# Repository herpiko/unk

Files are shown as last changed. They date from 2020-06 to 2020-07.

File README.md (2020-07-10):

# UNK



UNK stands for Ultimate Ngoprek Keyboard, my own version of <a href="https://ultimatehackingkeyboard.com/">UHK</a>. Hope this will be my endgame (I know it's a lie) keyboard. ~~This is still a work-in-progress build logs.~~ <a href="https://github.com/herpiko/unk/blob/master/README.md#build-logs">The build logs is nearly complete</a>.

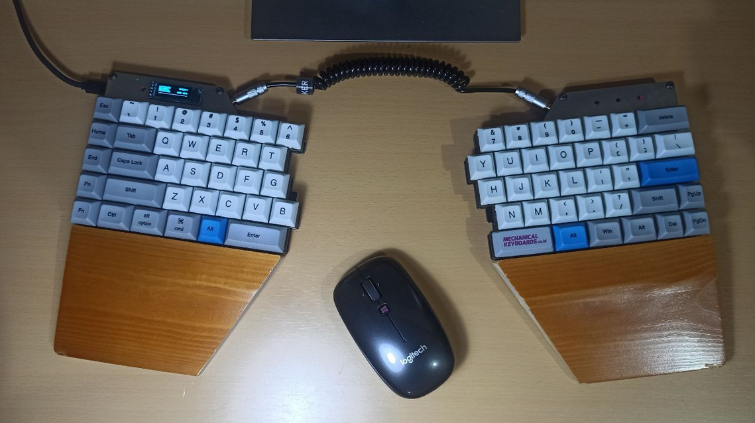
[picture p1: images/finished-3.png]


## Goals

- Cheap 👎
- As thin as possible (thinner than Vortex Core) 👎
- Fully programmable (QMK) ✅
- Almost zero learning curve (horizontally staggered, ~ortholinear~, ~symbols through modifier/layer~) ✅
- Ergonomic as UHK (splitted) ✅
- Generic size of keycaps (combinations from 104 keycaps set should be fitted) ✅
- Interchangeable middle modules (touchpad, trackball, smartphone dock) 👎

## Layout

- Combined : http://www.keyboard-layout-editor.com/#/gists/457787e3b1938c4cbe9d65c7b7bd31ef
- Left half: http://www.keyboard-layout-editor.com/#/gists/f117f3cbc2d0b1bf17206992068f9017
- Right half: http://www.keyboard-layout-editor.com/#/gists/e9e79566d1be71f77f1f2d33660011e5

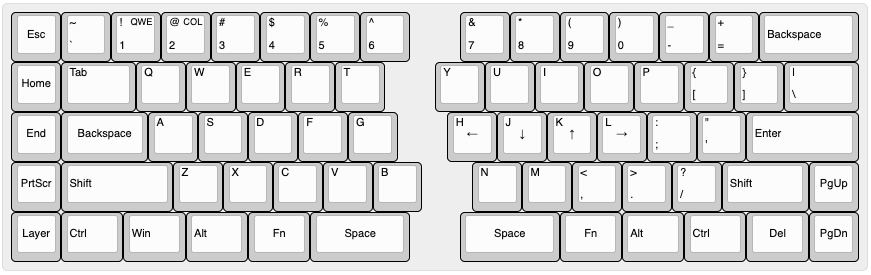
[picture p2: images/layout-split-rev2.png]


## Plate

Download:
- <a href="https://github.com/herpiko/unk/raw/master/unk-plate-layout.svg">SVG (Inkscape)</a>
- ~~<a href="https://github.com/herpiko/ultimate-ngoprek-keyboard/raw/master/split-full-final-cut.ai">Adobe Illustrator</a>~~

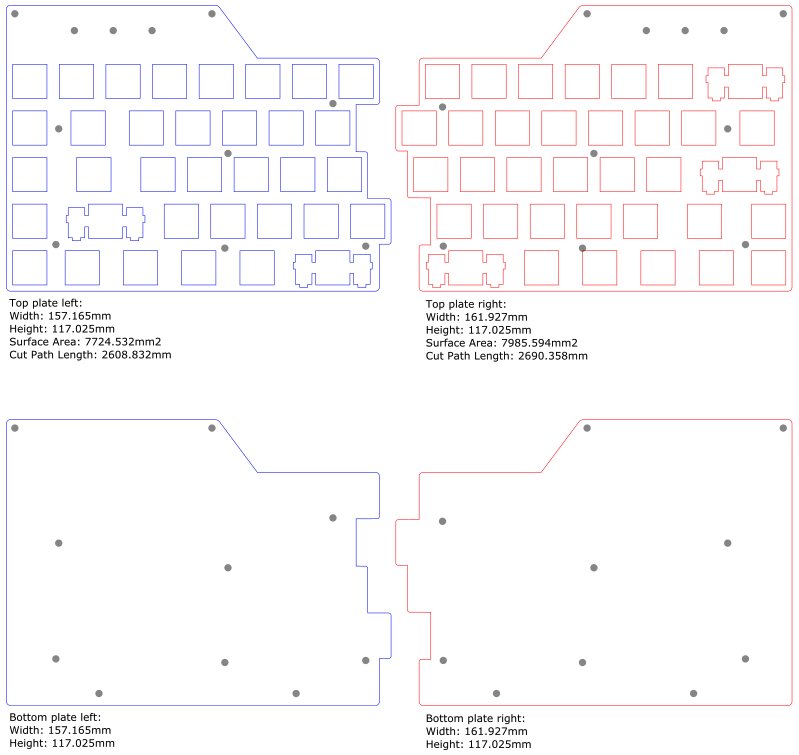
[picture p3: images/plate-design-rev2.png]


## Anatomy

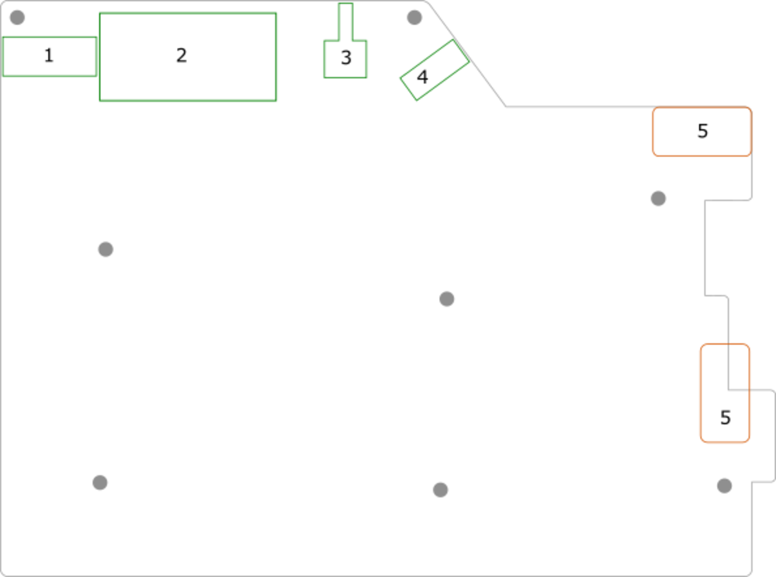
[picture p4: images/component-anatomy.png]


The greens are on the top plate. The oranges are on the bottom.

1. USB-C female to Micro USB male converter
2. Pro Micro clone
3. Tactile switch
4. TRRS jack
5. Neodymium magnets

## Parts

| Item  | Price (rupiah) |
| --- | ---: |
| I'm using existing DSA keycaps set from my <a href="https://www.google.com/search?q=vortex+tab+75&source=lnms&tbm=isch">Vortex Tab 75 keyboard</a>.<br/><br/>104 keycaps set is now supported. | 0 |
| <a href="https://www.tokopedia.com/vortexseries/ks-9-gateron-brown-switch-tactile-plate-mounted">Gateron Brown switches</a>, 80 @ Rp 2.400 | 192.000 |
| <a href="https://www.tokopedia.com/tokopuwei/dioda-in4148-1n-4148-in-4148-dip-diode-1n4148-do35-ac85-harga-1-pcs">IN4148 diodes</a>, 200 @ Rp 100 | 20.000 |
| <a href="https://www.tokopedia.com/solarperfect/pro-micro-promicro-atmega32u4-16mhz-5v-arduino-module">Pro micro ATMEGA32U4 16Mhz 5V</a>, 2 @ Rp 52.800 | 105.600 |
| Stainless steel plates + laser cutting service at <a href="https://www.instagram.com/laserindonesia/">Laser Indonesia</a>, 1.5mm top plate + 2.0mm bottom plate | 463.000 |
| ~~<a href="https://www.tokopedia.com/pixlup/genuine-cherry-pcb-mount-stabilizer-stabilizers-fullsize">Cherry switch stabilizers (1x6u, 6x2u)</a>~~  *<-- WRONG PART.* <a href="https://www.tokopedia.com/pixlup/genuine-cherry-plate-mount-stabilizers-stabilizer">The right one is the plate mount version.</a> | 210.000 |
| <a href="https://www.tokopedia.com/hpasesoris/m3x6mm-m3-6-black-nylon-hex-nut-m3-thread-female-standoff-spacer-aq21">M3 x 6mm female to female spacer</a>, 30 @ Rp 1.200 | 36.000 |
| <a href="https://www.tokopedia.com/pcmjakarta/kabel-tunggal-mini-tembaga-0-5mm-40meter">Single copper wire 0.5mm</a>, 40 meter | 30.000 |
| <a href="https://www.tokopedia.com/stickerkacafilm/stikerstickermotormobilstiker-karboncarbon3d-hitam-dof">Carbon vinyl sticker 30 meter</a> | 45.000 |
| <a href="https://www.tokopedia.com/kiddiesworld123/magnet-super-neodymium-kepingan-persegi-kotak-ndfeb-20-x-10-x-2-mm">Neodymium super magnet 20 x 10 x 2mm</a>, 16 @ Rp 3.700 | 59.200 |
| <a href="https://www.tokopedia.com/adelioberkah/baut-screw-kecil-m3x3-laptop-hp-toshiba-dell-samsung-asus-acer-lenovo">M3x3mm screw for top plate</a>, 20 @ Rp 3.000 | 60.000 |
| <a href="https://www.tokopedia.com/crd/m3-x-5mm-button-head-hex-screw-1pcs-baut-hex-m3x5mm-1pcs">M3x5mm hex screw for bottom plate</a>, 30 @ Rp 1.500 | 45.000 |
| <a href="https://www.bukalapak.com/p/komputer/aksesoris-226/keyboard/6ere8e-jual-wood-wrist-rest-for-tenkeyless-size-mechanical-keyboard-brown">Wood wrist rest for TKL size mechanical keyboard (36cm)</a> | 100.000 |
| <a href="https://www.tokopedia.com/qacc/type-c-to-microusb-adapter-converter-otg-adaptor-type-c-to-micro-usb">Type C USB to micro USB adapter</a>, 2 @ Rp 15.000 | 30.000 |
| <a href="https://www.bukalapak.com/p/elektronik/komponen-elektronik/zzdmgd-jual-tactile-switch-push-button-saklar-tekan-6x6x10-mm-arduino-elektronika-bread-board-pcb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">Tactile switch push button 6 x 6 x 10mm</a>, 2 @ Rp 2.800 | 5.600 |
| <a href="https://www.tokopedia.com/myofficialstore0/trrs-pcb-3-5mm-breakout-jack-headset-headphone-earphone-socket-diy-merah">TRRS PCB 3.5mm jack socket</a>, 2 @ Rp 12.000 | 24.000 |
| <a href="https://www.tokopedia.com/herzhz/35mm-trrs-4-pole-for-hifiman-balanced-male-plug-jack-35">3.5mm TRRS 4 pins male plug</a>, 2 @ Rp 12.500 | 25.000 |
| <a href="https://www.tokopedia.com/optimuspri/joyseus-2-in-1-coiled-data-cable-1-m-micro-usb-type-c">Joyseus 2 in 1 coiled data cable 1M (micro USB & type C)</a> | 45.000 |
| <a href="https://www.tokopedia.com/3mtapes/3m-sj-5306-bumpon-clear">3M SJ-5306 Bumpon Clear</a> | 18.000 |
| <a href="https://www.tokopedia.com/isee/new-091-091-inch-inchi-128x32-oled-white-display-lcd-module-slim">128x32 pixel OLED white display</a> | 35.000 |

*The list is excluding shipping cost and wrong parts those I purchased. Some items were purchased more than the need for spare/stockpile. If the whole things counted, it reached almost 2 million rupiahs.*

## Firmware

UNK firmware code is now registered under QMK's handwired section.

### Preparation
```
$ git clone https://github.com/qmk/qmk_firmware.git
$ ./util/qmk_install.sh
```

### Compile
```
$ make handwired/unk/rev1:default
```

### Flashing the left half

Press the reset button twice and fast, then:
```
$ sudo avrdude -p atmega32u4 -c avr109 -U ./.build/handwired_unk_rev1_default.hex -P /dev/ttyACM0

```

### Flashing the right half

Uncomment the line that state `#define MASTER_LEFT` in `keyboards/handwired/unk/rev1/config.h`, then:

```
$ make handwired/unk/rev1:default
```

Press the reset button twice and fast, then:

```
$ sudo avrdude -p atmega32u4 -c avr109 -U ./.build/handwired_unk_rev1_default.hex -P /dev/ttyACM0
```
## Usage

- `Layer` + `Home` to switch to Qwerty layout
- `Layer` + `End` to switch to Colemak layout

## Useful links

The sources I read and inspired me for building this keyboard:

- Keyboard layout editor, http://www.keyboard-layout-editor.com/
- Plate builder, http://builder.swillkb.com/
- Laser cutting service, https://lasergist.com/shop/lasergist/
- Acrylic laser cutting service, https://www.tokopedia.com/kencanagrafikama/akrilik-acrylic-3mm-potongan-custom-putih-susu
- Pro micro official guides/FAQ, https://learn.sparkfun.com/tutorials/pro-micro--fio-v3-hookup-guide/troubleshooting-and-faq
- Promethium51, https://priyadi.smugmug.com/Mechanical-Keyboard/Promethium-Keyboard/Build-Log/n-4fFNQC
- Handwiring split guide based on lets_split, https://johannes-jansson.github.io/projects/2018/07/23/hand-wiring-lets-split.html
- Handwiring guide, https://geekhack.org/index.php?topic=87689.0
- https://www.reddit.com/r/olkb/comments/5s8q76/help_pro_micro_pinout_for_qmk/
- Thinkpad trackpoint,
  - https://electronics.stackexchange.com/questions/189790/determining-trackpoint-pinout
  - https://github.com/qmk/qmk_firmware/tree/master/keyboards/handwired/trackpoint
  - https://github.com/alonswartz/trackpoint
  - https://github.com/alonswartz/trackpoint#tmk-firmware-changes-and-tweaks
  - https://docs.qmk.fm/#/feature_ps2_mouse
  - https://deskthority.net/wiki/TrackPoint_Hardware#ThinkPad_R61_TrackPoint
- Pro micro built-in LEDs, https://www.electronicsweekly.com/blogs/engineer-in-wonderland/arduino-micro-direct-access-board-leds-2017-08/
- TRRS in  Pro Micro + QMK, https://beta.docs.qmk.fm/using-qmk/hardware-features/feature_split_keyboard
- Blackberry trackpad, https://vlukash.com/2019/01/15/trackpad-in-keycap-corne-crkbd-keyboard/
- Adding layers, https://thomasbaart.nl/2018/12/06/qmk-basics-how-to-add-a-layer-to-your-keymap/
- Layers, https://jayliu50.github.io/qmk-cheatsheet/
- VIA configurator, https://gist.github.com/nooges/5878b2648b6daeefb5c44d4ec16bf912

## Build Logs

### 20200612

The wish was occured a loooooong time ago but I began to (seriously) design the keyboard from this date. I also started to purchase the parts that I need to build the keyboard.

### 20200615

Pro micro clones arrived. Small important things.

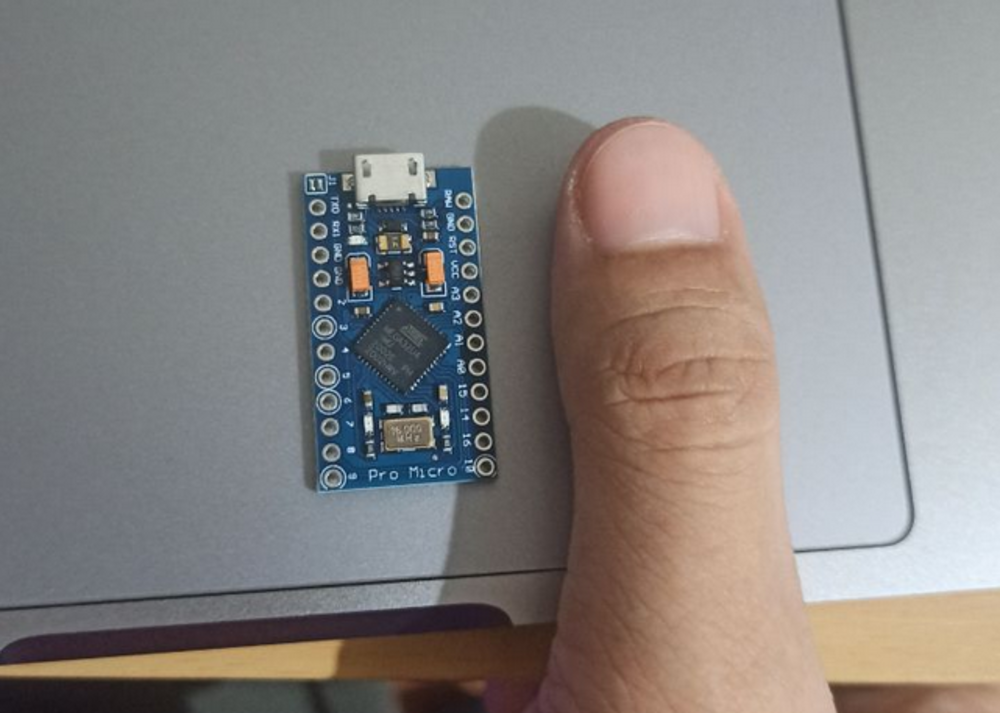
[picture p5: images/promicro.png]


### 20200617

The plates arrived. The top plate's thickness is 1.5mm and the bottom plate is 2mm. I'm a bit surprissed that these plates were quite heavy. Heavy (p)unk keyboard!

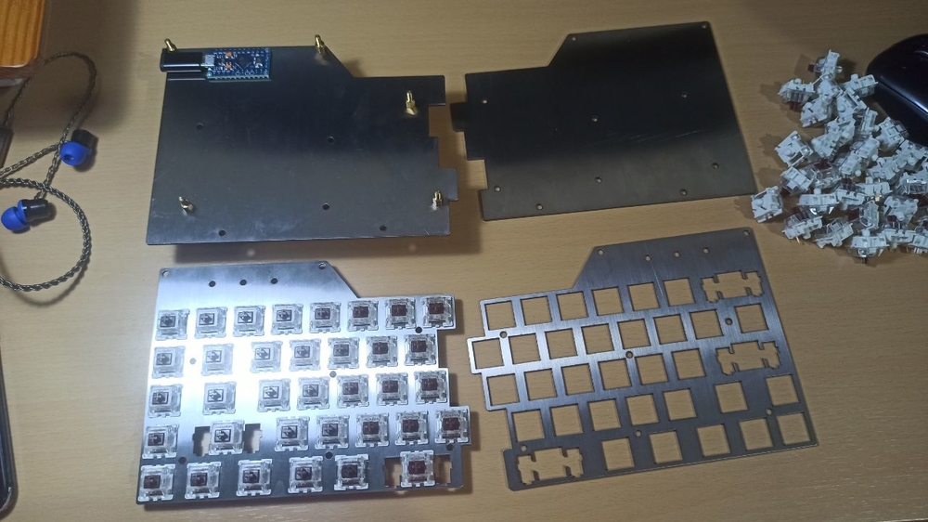
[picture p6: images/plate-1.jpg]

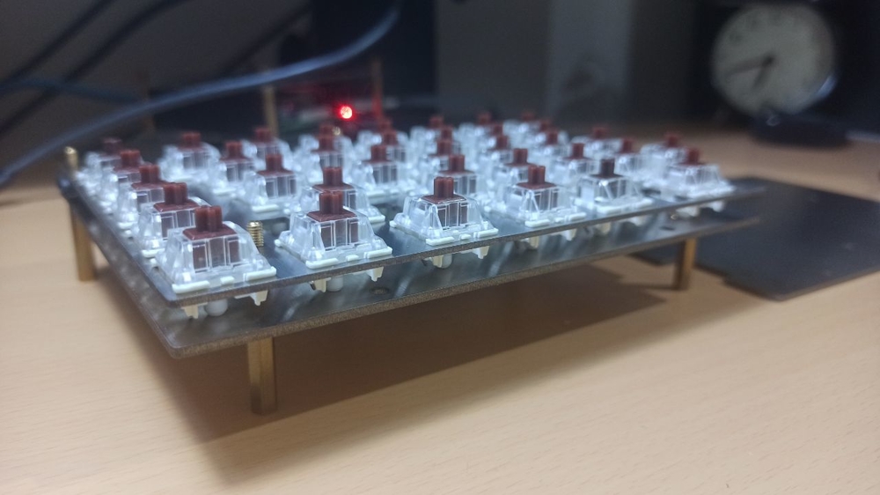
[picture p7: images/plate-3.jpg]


### 20200619

I put carbon-like sticker on the inner side of bottom plate to avoid shorting from the wiring.

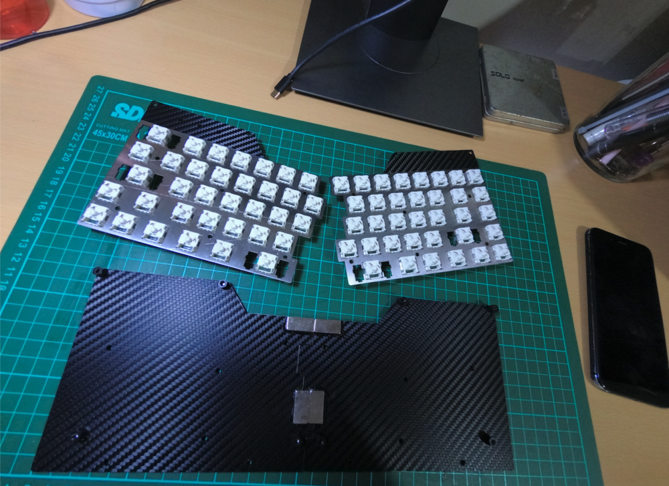
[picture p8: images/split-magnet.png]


Also there were four strong neodymium magnets to help the two parts stick together.



### 20200620

Handwired. Pardon my mediocre soldering skill.

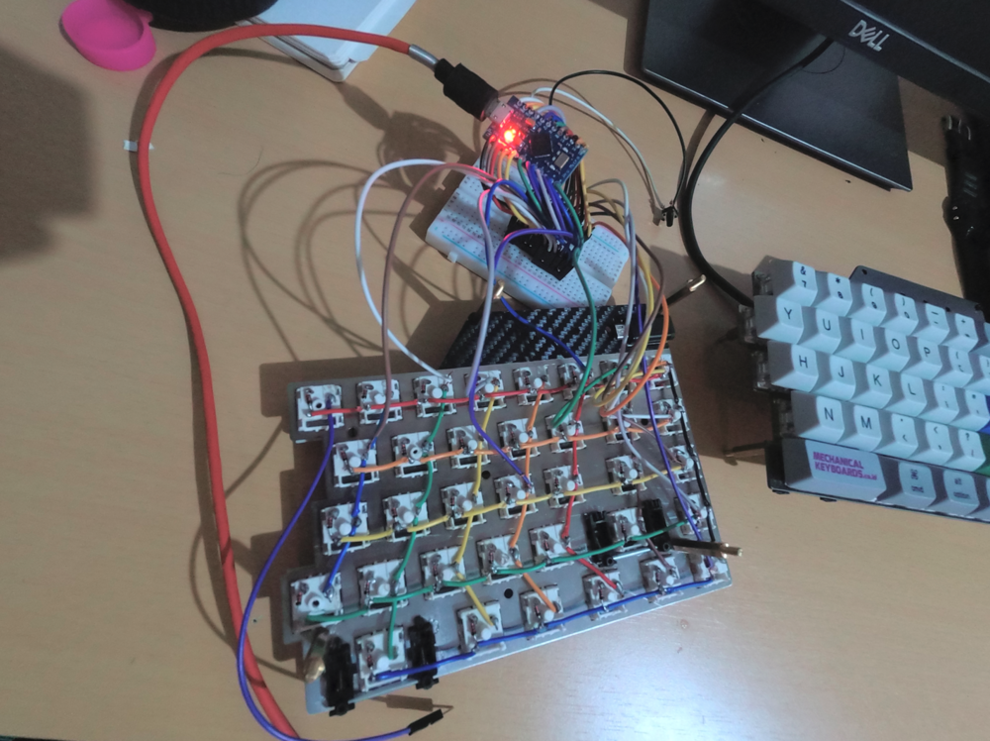
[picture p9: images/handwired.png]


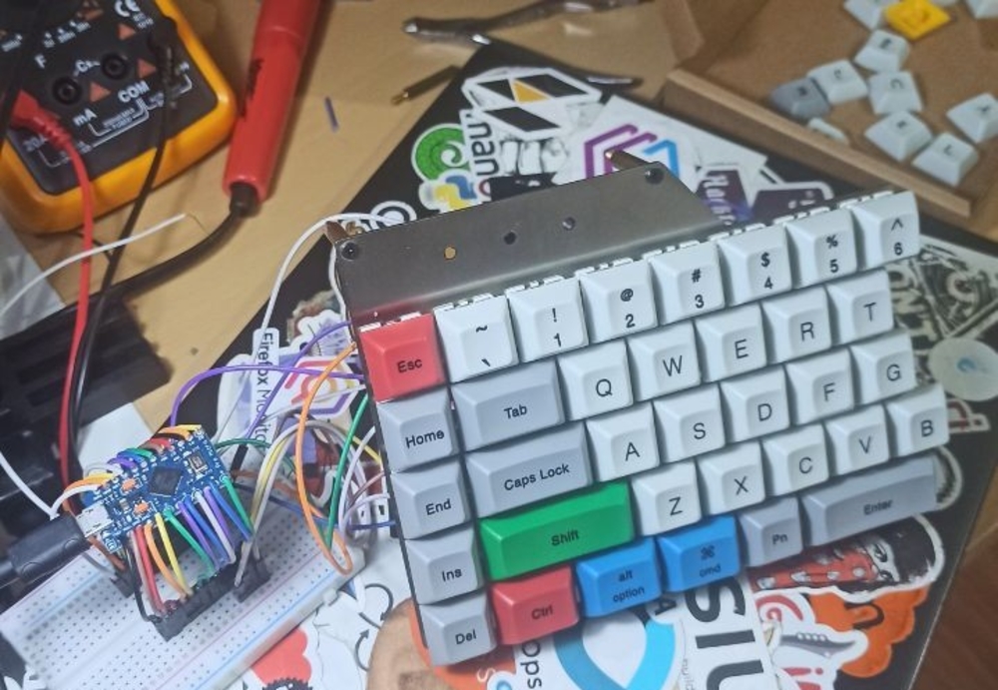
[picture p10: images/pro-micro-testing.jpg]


### 20200622

Fully working left half. I was still playing and learn how to work with QMK firmware code.



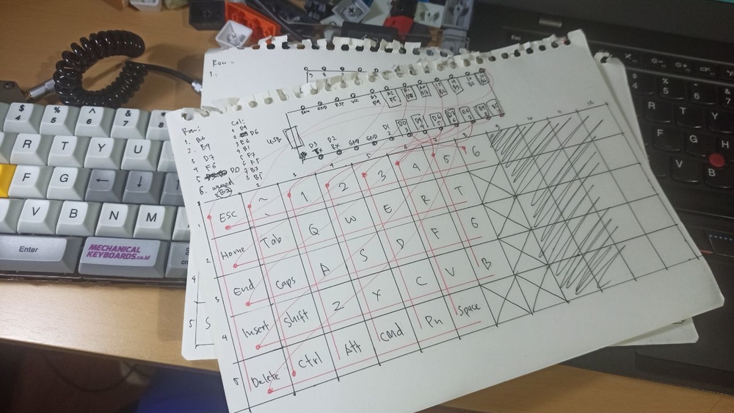
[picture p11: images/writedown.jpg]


### 20200623

DO NOT USE SUPER GLUE TO GLUE YOUR SWITCHES TO THE PLATE.

Oh boy, just don't. I'm a big fan of super glue as it's very versatile, strong adhesive, and quick-drying. Super glue has this kind of vapor that makes white mark around the surface that you glued on. My super glue is the strong one. This marks got into my switches' housing, contaminated the copper contacts, and makes it unusable!

Because of my stupidity, I've to unplugged all the switches. I've to redo all the works that has been done on switches: matrix soldering and gluing. Plentiful of switches become the victims. Huft!

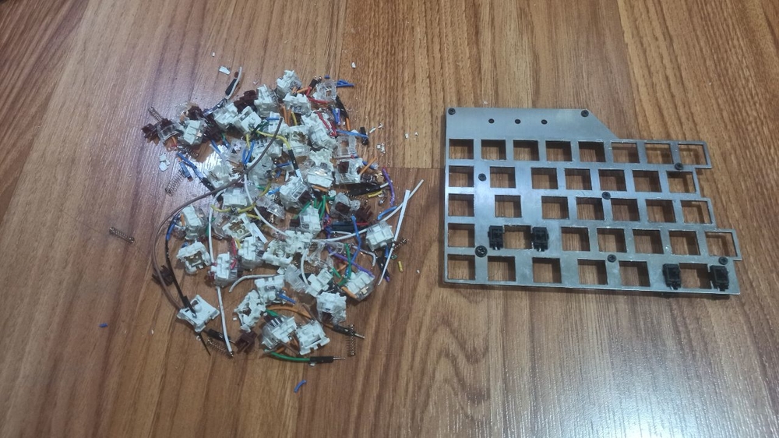
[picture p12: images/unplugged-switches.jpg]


Use hot glue instead. Hot glue is quite strong to hold your switches but very easy to remove in case that you want to change some bad switches.

I'll use super glue only to things that need strong hold on the plate like USB-C port. reset tactile switch,  TRRS jack.

I've seen some videos of making handwired keyboard and got some idea for better handwiring. I'll be using ~~0.35mm magnet coil wire~~ single core copper wire.

### 20200624

Need to cut out the height of the switches and stabilizer so I can push the  thickness limit. It'll be using 6mm spacer. The original uncut version is on the left. The middle is the common cut. The right one was forced to be cut like that to make more room for the neodymium magnet.

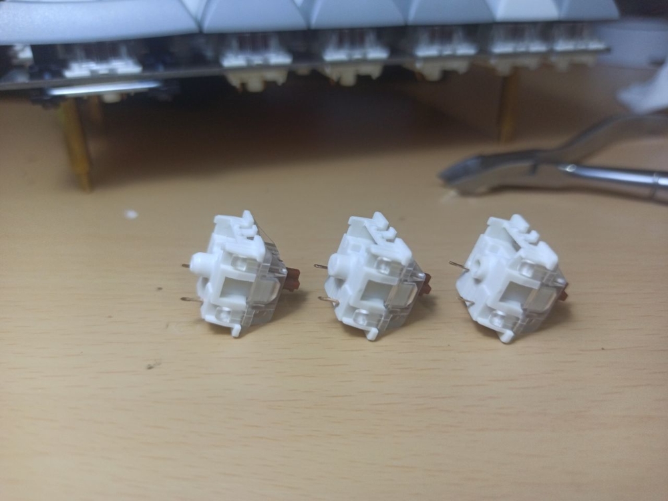
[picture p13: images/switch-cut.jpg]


I noticed lately that I purchased the wrong stabilizer. I should use the plate mount version instead of PCB mount.

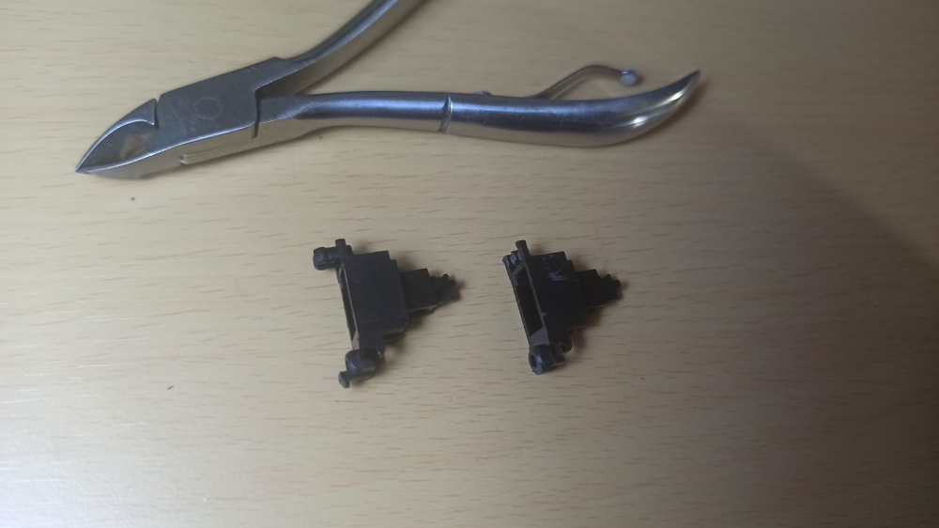
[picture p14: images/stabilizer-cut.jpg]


I reglued the switches back into the plate using hot glue. Quite easy but messy. Note that you have to clean the "spider web" things from the hot glue. If this thing makes it way into your switch housing or the stabilizer, it'll makes it feels terrible.

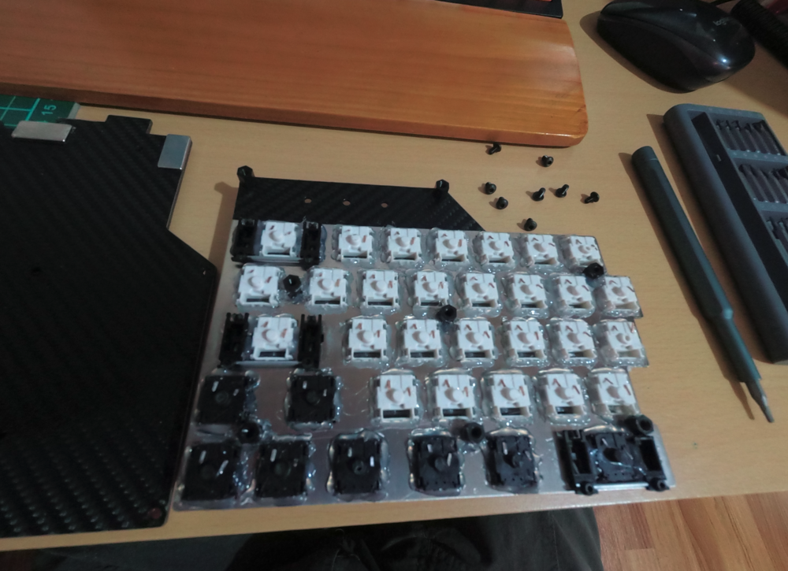
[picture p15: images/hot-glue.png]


### 20299625

While waiting for the wire to be arrived, I made a pair of wrist rest from an unused one.

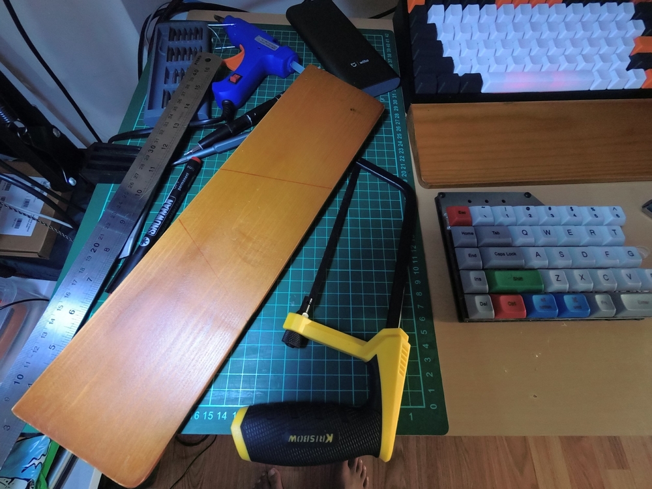
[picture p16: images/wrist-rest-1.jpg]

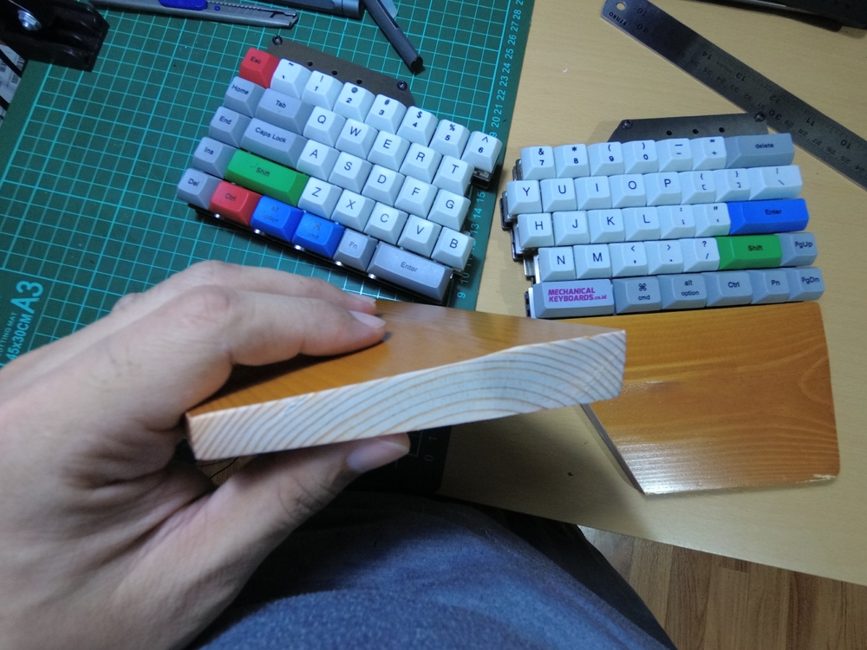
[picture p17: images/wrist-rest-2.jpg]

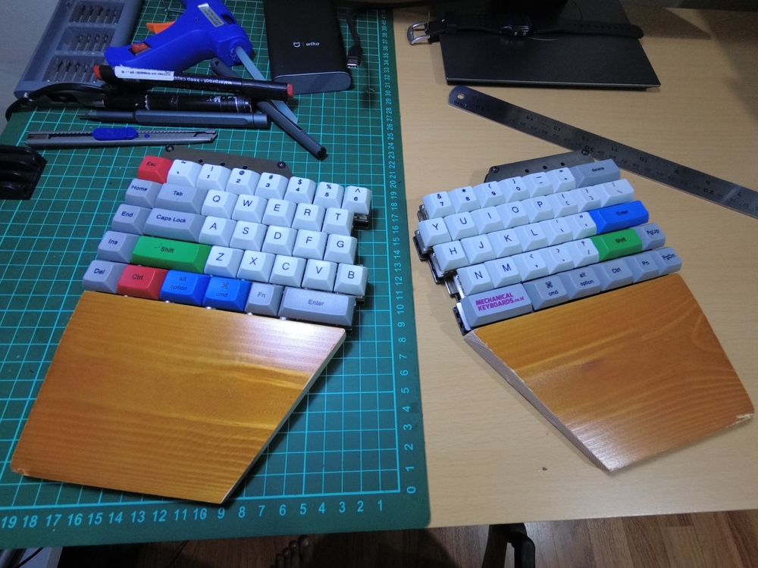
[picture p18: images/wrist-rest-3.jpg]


The TRRS cable was also being made.

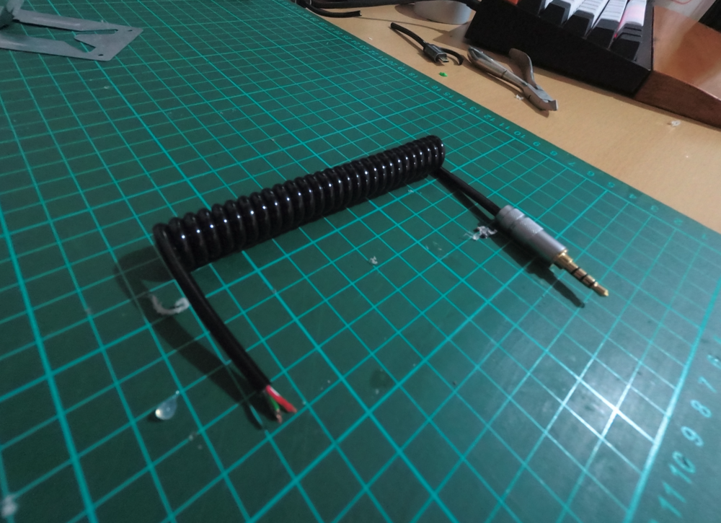
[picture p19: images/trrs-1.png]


Turned out that the TRRS jack is too thick for 6mm spacer. I need to set apart the jack port from the PCB.

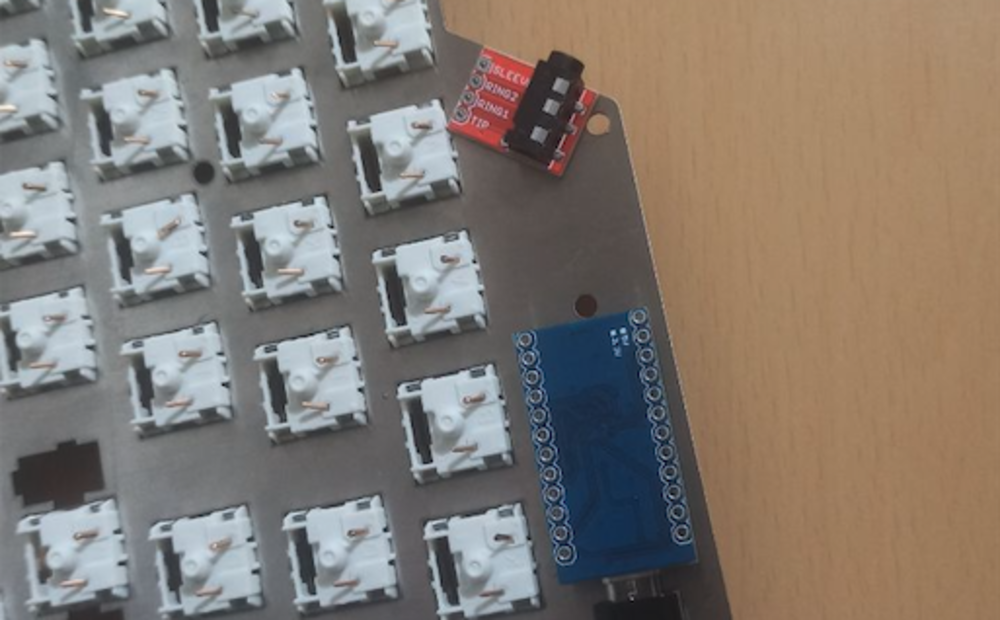
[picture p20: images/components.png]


### 20200627

Fully handwired.

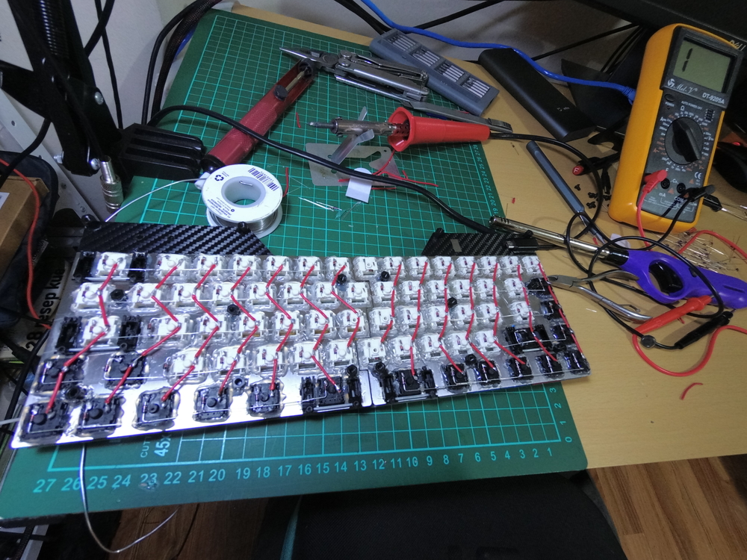
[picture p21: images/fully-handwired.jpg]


Components placement. Glued with super glue (except for the Pro micros).

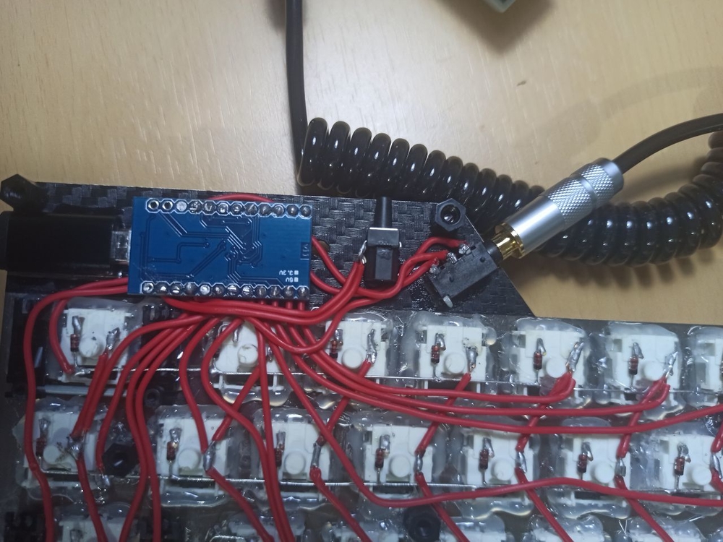
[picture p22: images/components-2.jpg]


Bumpons added as rubber foot. Also another neodymium magnet to force the wrist rest stick with the board.

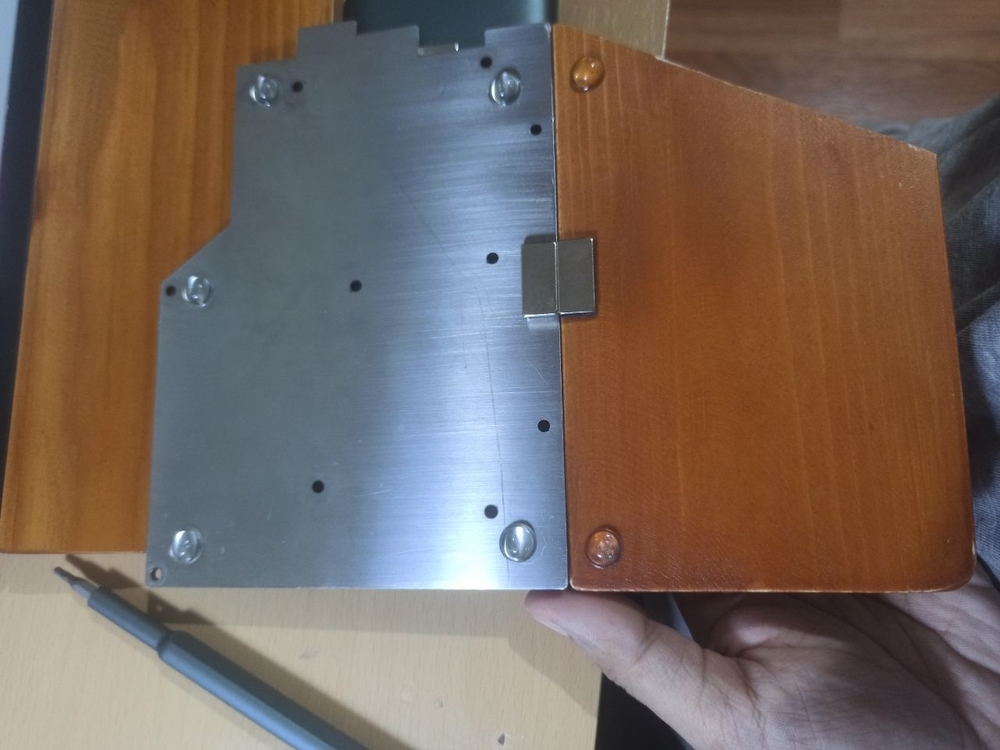
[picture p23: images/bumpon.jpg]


Multimeter tool is a must here. Need to check the entire wiring carefully.

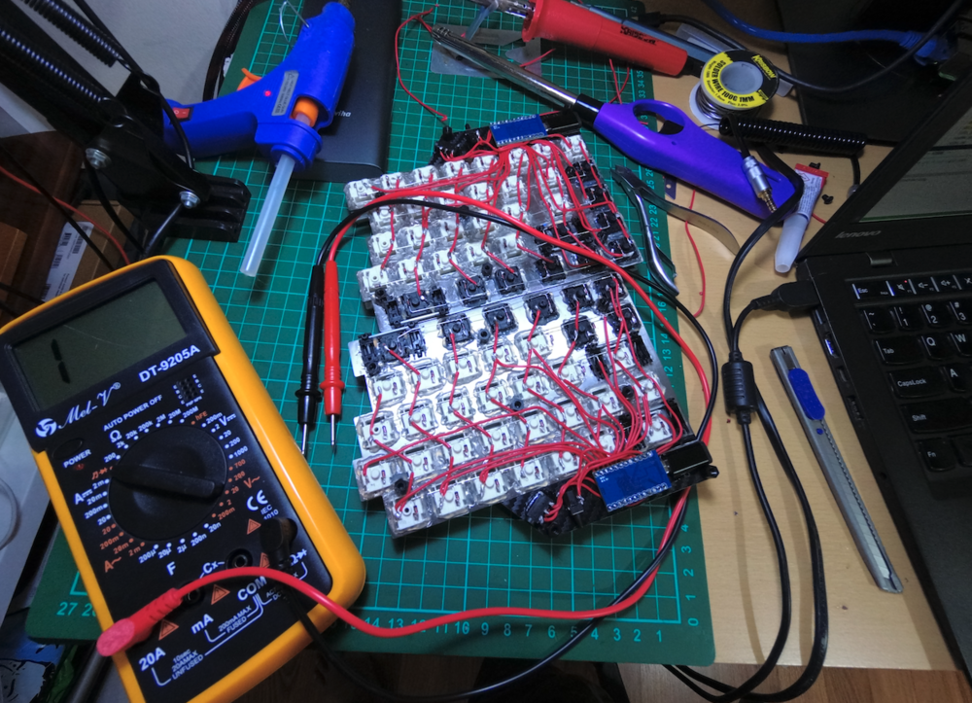
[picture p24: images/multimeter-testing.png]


I found an inverted diode and fixed it.

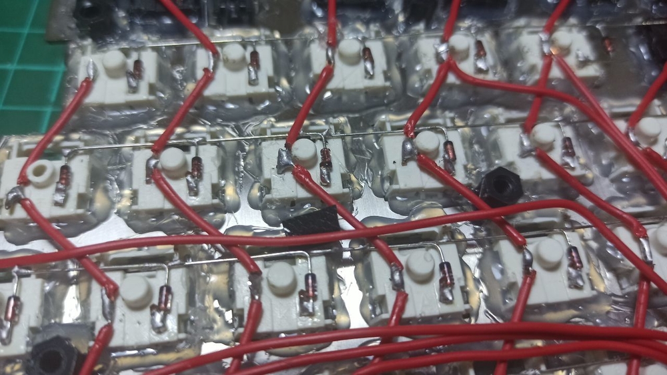
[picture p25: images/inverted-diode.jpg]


Forgot that the neodymium magnet's coating is conductive so I put the sticker on these too.

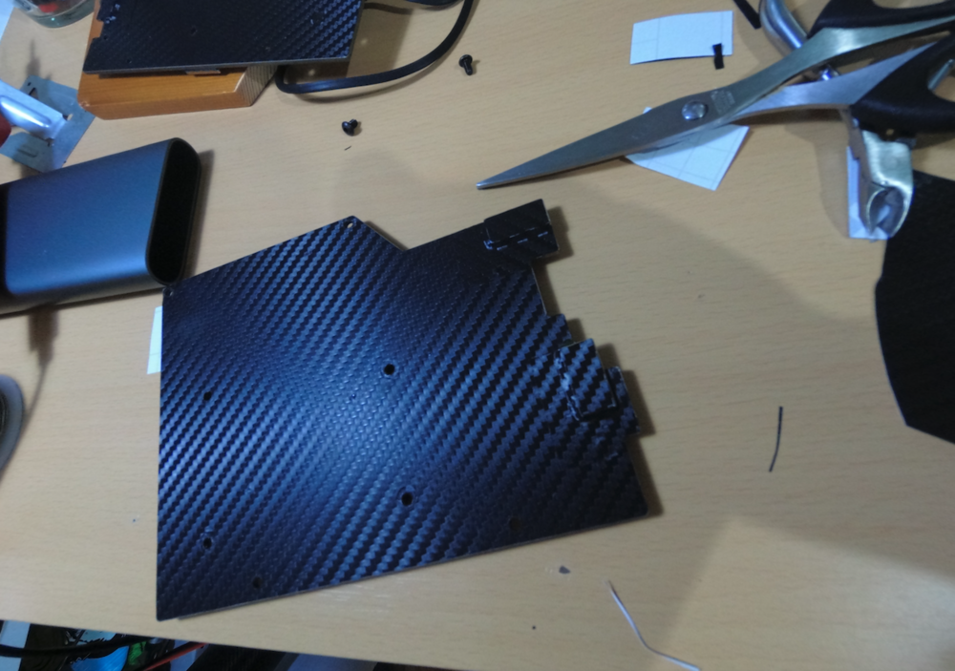
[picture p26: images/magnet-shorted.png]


Entering programming phase. QMK is fun. I'm using deltasplit75 as the base.

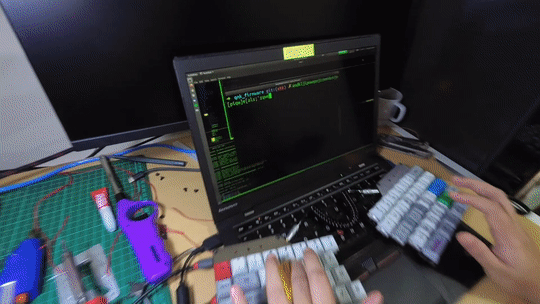
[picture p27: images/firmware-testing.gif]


Side views. You can see that the reset button is easy to reach with your nail.

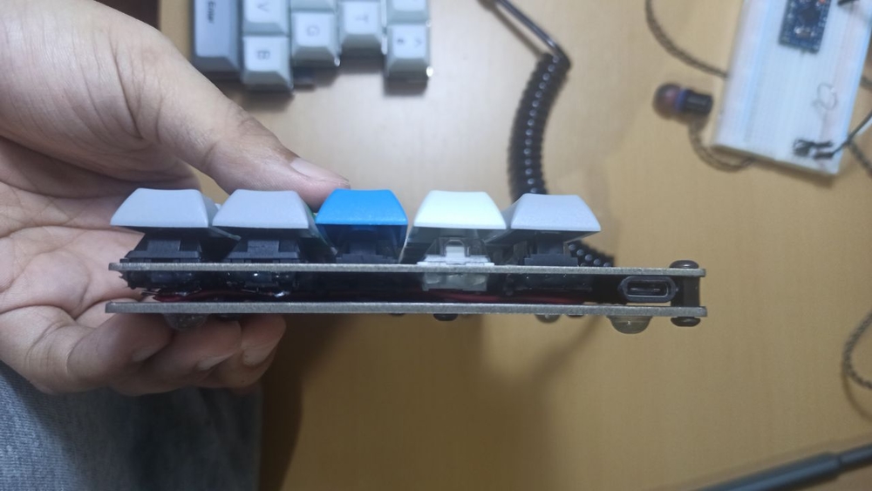
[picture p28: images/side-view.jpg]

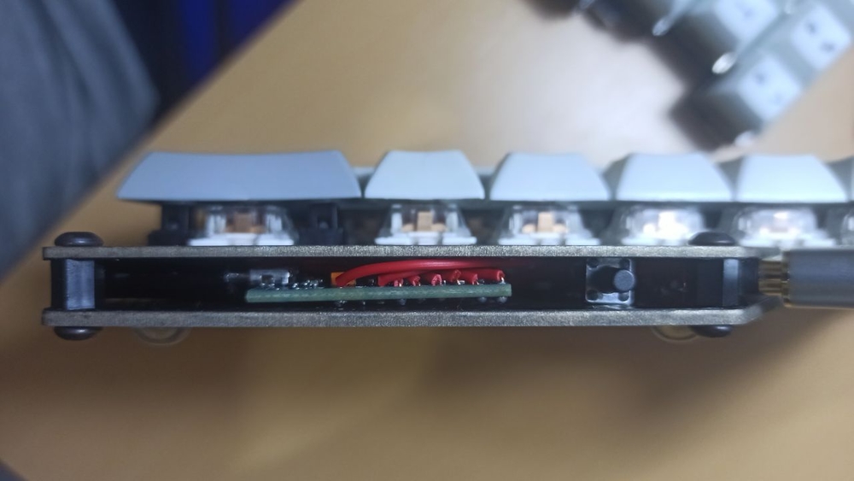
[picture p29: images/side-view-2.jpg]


All the keys has been tested.

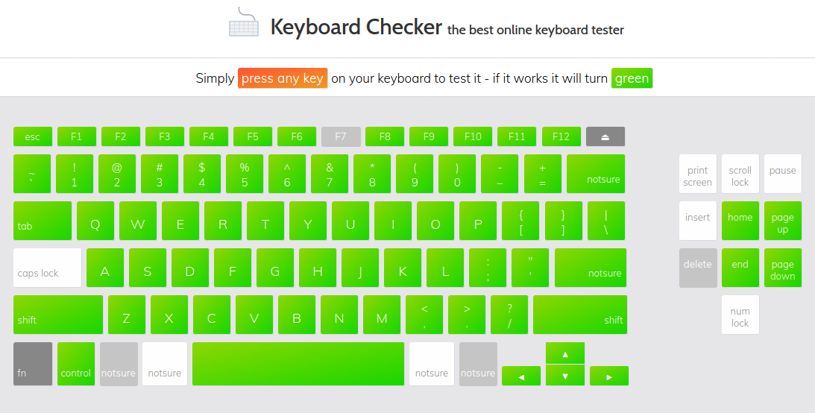
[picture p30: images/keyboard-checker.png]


Finished!

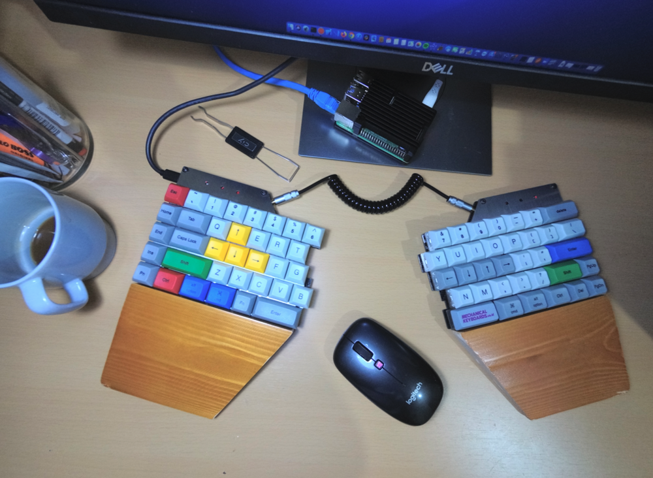
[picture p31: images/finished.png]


### 20200629

My first day using UNK at work, https://www.youtube.com/watch?v=z-LAlFVbLv8. This is the first time ever I typed on split keyboard for long hours.

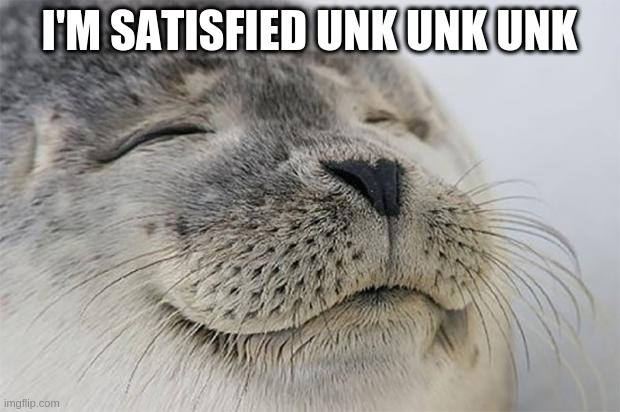
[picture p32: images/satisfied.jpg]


I also send <a href="https://github.com/qmk/qmk_firmware/pull/9571">pull request</a> to QMK to register UNK under handwired section.

### 20200630

<a href="https://github.com/qmk/qmk_firmware/commit/6d6340a82b3ed61f5dd2a40dac78712d7bd736fd">My pull request has been merged.</a> I think the first iteration of UNK is done for now. Thanks!

### 20200704

I've updated the layout and plate design. UNK is now supporting 104 keycaps set by resizing its space keys to 2u. `+` and `Ent` keys from the numpad can be used here. On the other hand left `Fn` and `Del` keys got bigger. DSA profile is preferred for best suitability.

### 20200706

UNK is now having mini OLED display so I'll know which layer is on. Just like UHK, eh?

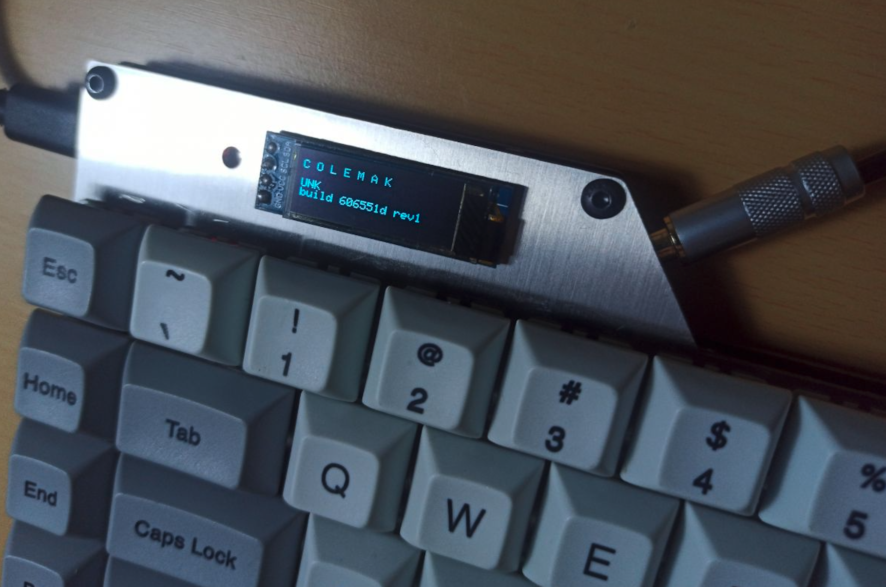
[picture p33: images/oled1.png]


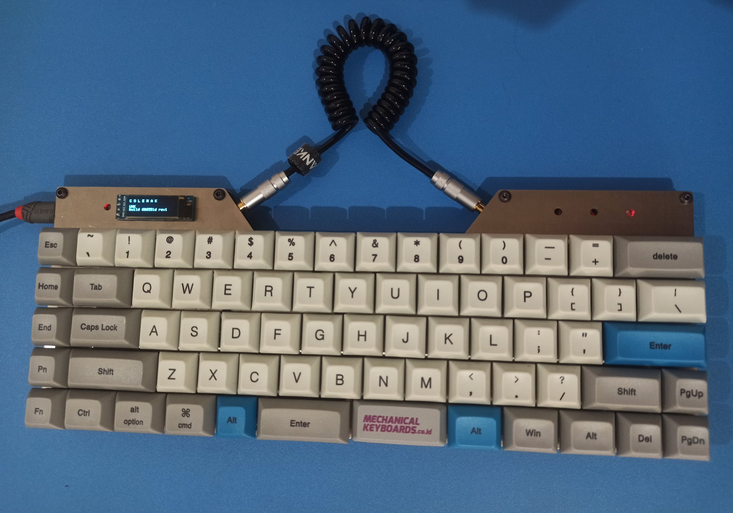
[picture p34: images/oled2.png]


## License

All images and SVG file that I produced are under CC-BY-SA. QMK related code is under GPL. The QMK Firmware logo is a trademark of QMK.

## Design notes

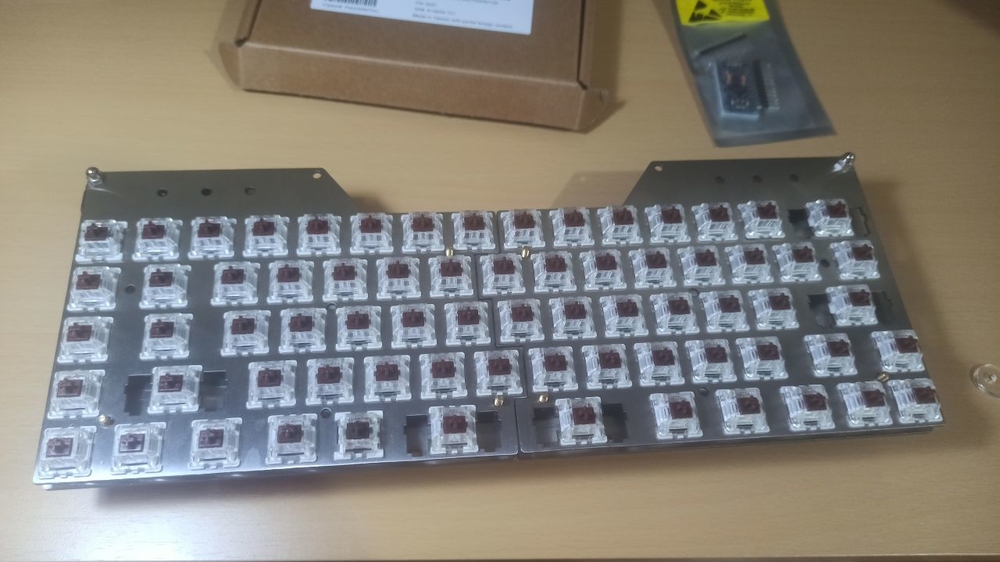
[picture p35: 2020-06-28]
images/plate-4.jpg

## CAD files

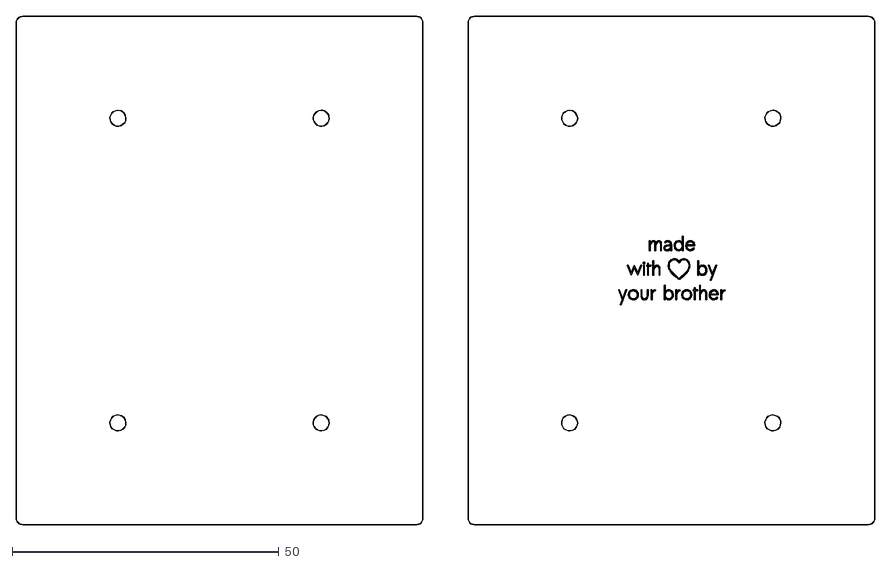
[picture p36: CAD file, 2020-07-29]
numpad.dxf
160.9 x 95.3

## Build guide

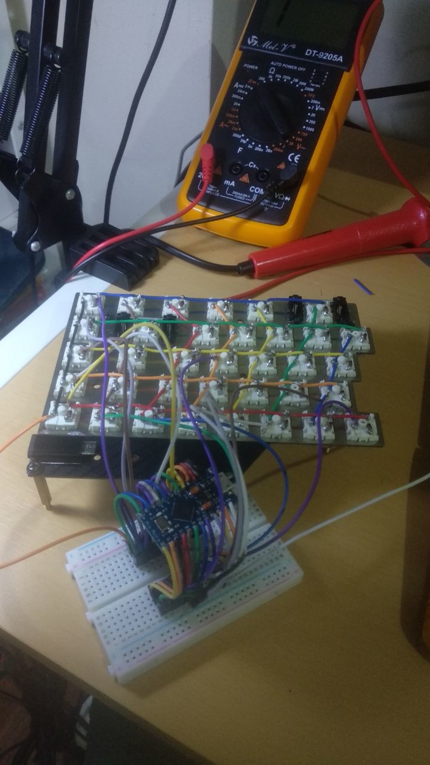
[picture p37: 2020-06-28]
images/matrix-soldered.jpg

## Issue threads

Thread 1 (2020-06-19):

Notes

herpiko, 2020-06-19:
- Keyboard layout editor, http://www.keyboard-layout-editor.com/
- Plate builder, http://builder.swillkb.com/
- Laser cutting service, https://lasergist.com/shop/lasergist/
- Pro micro official guides/FAQ, https://learn.sparkfun.com/tutorials/pro-micro--fio-v3-hookup-guide/troubleshooting-and-faq
- Handwiring split guide based on lets_split, https://johannes-jansson.github.io/projects/2018/07/23/hand-wiring-lets-split.html
- Handwiring guide, https://geekhack.org/index.php?topic=87689.0
- https://www.reddit.com/r/olkb/comments/5s8q76/help_pro_micro_pinout_for_qmk/
- Thinkpad trackpoint, https://electronics.stackexchange.com/questions/189790/determining-trackpoint-pinout
- Pro micro built-in LEDs, https://www.electronicsweekly.com/blogs/engineer-in-wonderland/arduino-micro-direct-access-board-leds-2017-08/
- TRRS in  Pro Micro + QMK, https://beta.docs.qmk.fm/using-qmk/hardware-features/feature_split_keyboard
- Blackberry trackpad, https://vlukash.com/2019/01/15/trackpad-in-keycap-corne-crkbd-keyboard/
- Adding layers, https://thomasbaart.nl/2018/12/06/qmk-basics-how-to-add-a-layer-to-your-keymap/
- Layers, https://jayliu50.github.io/qmk-cheatsheet/

herpiko, 2020-06-19:
https://www.reddit.com/r/olkb/comments/5s8q76/help_pro_micro_pinout_for_qmk/

herpiko, 2020-06-19:
- https://electronics.stackexchange.com/questions/189790/determining-trackpoint-pinout

herpiko, 2020-06-20:
- Pro micro built-in LEDs, https://www.electronicsweekly.com/blogs/engineer-in-wonderland/arduino-micro-direct-access-board-leds-2017-08/

herpiko, 2020-06-21:
- TRRS in  Pro Micro + QMK, https://beta.docs.qmk.fm/using-qmk/hardware-features/feature_split_keyboard

herpiko, 2020-06-23:
- Blackberry trackpad, https://vlukash.com/2019/01/15/trackpad-in-keycap-corne-crkbd-keyboard/

herpiko, 2020-06-27:
Serial communication issue:
- Make sure the connection with multimeter
- Set MASTER_LEFT on left half, but don't set any on right half.

herpiko, 2020-06-28:
- Adding layers, https://thomasbaart.nl/2018/12/06/qmk-basics-how-to-add-a-layer-to-your-keymap/

herpiko, 2020-06-28:
- Layers, https://jayliu50.github.io/qmk-cheatsheet/

Closed 2020-07-02.

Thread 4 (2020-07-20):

Why no ISO style keyboard?

Supermagnum, 2020-07-20:
Hello, as there are no ISO style keyboards that are split and ergonomic I think that it is a good idea to make that available. It is clearly a marketing opportunity there.
Here is my version of a non-split keyboard in ISO style, with Norwegian QWERTY and Dvorak.
It doesn't have a num pad, but some people may want that.
http://www.keyboard-layout-editor.com/#/gists/53284f72c23040b29def237b7399e567

herpiko, 2021-05-31:
You only need to modify the plate's SVG file to do this. The rest is very easy/customizable since this is a handwired keyboard.

Closed 2021-05-31.

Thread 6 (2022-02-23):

Support

BetaMaxHeadroom, 2022-02-23:
Hi,

This looks incredible. I especially like that I can move the TrackPoint module around to where it is most comfortable for me. The UHK seems to only allow you to use your thumb. And, I am too accustomed to using my index finger to change now.

I see from the picture that F7 does not show up as green. Were you able to get that to work?

I'd really like to support your project. Do you happen to have a site where I could purchase the keyboard and TrackPoint module? My wrists would certainly appreciate it.

herpiko, 2023-03-15:
@BetaMaxHeadroom

Hi,

Sorry for the late response.

> This looks incredible. I especially like that I can move the TrackPoint module around to where it is most comfortable for me. The UHK seems to only allow you to use your thumb. And, I am too accustomed to using my index finger to change now.

Thank you! The TrackPoint is the hardest part because there are several PCB version of the TrackPoint and I think I'm lucky to get the one that have documentation around the internet. I have a spared TrackPoint PCB with different version around but I have not tried to wiring it into a working device.

> I see from the picture that F7 does not show up as green. Were you able to get that to work?

All keys were work as intended.

> I'd really like to support your project. Do you happen to have a site where I could purchase the keyboard and TrackPoint module? My wrists would certainly appreciate it.

I think I can help you to build one and I think now is the right time to do this because I'm on my way to rebuild the keyboard (fixing some issue, cutting the new stainless steel plates, and so on).

Please reach me at herpiko@gmail.com for further discussion.

Closed 2023-03-19.

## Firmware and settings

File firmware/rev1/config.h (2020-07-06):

/*
Copyright 2020 Herpiko Dwi Aguno <herpiko@gmail.com>

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
You should have received a copy of the GNU General Public License
along with this program.  If not, see <http://www.gnu.org/licenses/>.
*/

#pragma once

#include "config_common.h"

/* USB Device descriptor parameter */
#define VENDOR_ID       0xFEED
#define PRODUCT_ID      0x3060
#define DEVICE_VER      0x0001
#define MANUFACTURER    herpiko
#define PRODUCT         UNK
#define DESCRIPTION     70% split keyboard

/* key matrix size */
// Rows are doubled-up
#define MATRIX_ROWS 10
#define MATRIX_COLS 8



//#define MASTER_LEFT // Comment this line for the right half firmware

// wiring of each half
#define MATRIX_ROW_PINS { F5, B1, F6, B3, F7 }
#define MATRIX_COL_PINS { B2, B6, D4, C6, D7, E6, B4, B5 }
#define MATRIX_ROW_PINS_RIGHT { C6, D7, B4, E6, D4 }
#define MATRIX_COL_PINS_RIGHT { B1, B3, B2, B6, F7, B5, F6, F5 }


/* COL2ROW or ROW2COL */
#define DIODE_DIRECTION COL2ROW

/*
 * Split Keyboard specific options, make sure you have 'SPLIT_KEYBOARD = yes' in your rules.mk, and define SOFT_SERIAL_PIN.
 */

#define USE_SERIAL

// Because we are using OLED on I2C.
// USE_I2C does not to be defined here since OLED_DRIVER_ENABLE has been set in rules.mk
#define SOFT_SERIAL_PIN D3
#define SELECT_SOFT_SERIAL_SPEED 1

/* define if matrix has ghost */
//#define MATRIX_HAS_GHOST

/* number of backlight levels */
// #define BACKLIGHT_LEVELS 3

/* Set 0 if debouncing isn't needed */
#define DEBOUNCE 5

/* Mechanical locking support. Use KC_LCAP, KC_LNUM or KC_LSCR instead in keymap */
#define LOCKING_SUPPORT_ENABLE
/* Locking resynchronize hack */
#define LOCKING_RESYNC_ENABLE

/* ws2812 RGB LED */
#define RGB_DI_PIN D3

#define RGBLED_NUM 12    // Number of LEDs

/*
 * Feature disable options
 *  These options are also useful to firmware size reduction.
 */

/* disable debug print */
// #define NO_DEBUG

/* disable print */
// #define NO_PRINT

/* disable action features */
//#define NO_ACTION_LAYER
//#define NO_ACTION_TAPPING
//#define NO_ACTION_ONESHOT
//#define NO_ACTION_MACRO
//#define NO_ACTION_FUNCTION

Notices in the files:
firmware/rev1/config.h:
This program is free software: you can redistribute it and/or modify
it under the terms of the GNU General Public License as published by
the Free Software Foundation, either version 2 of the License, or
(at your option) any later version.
